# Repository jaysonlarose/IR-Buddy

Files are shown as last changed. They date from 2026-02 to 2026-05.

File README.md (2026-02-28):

# IR-Buddy

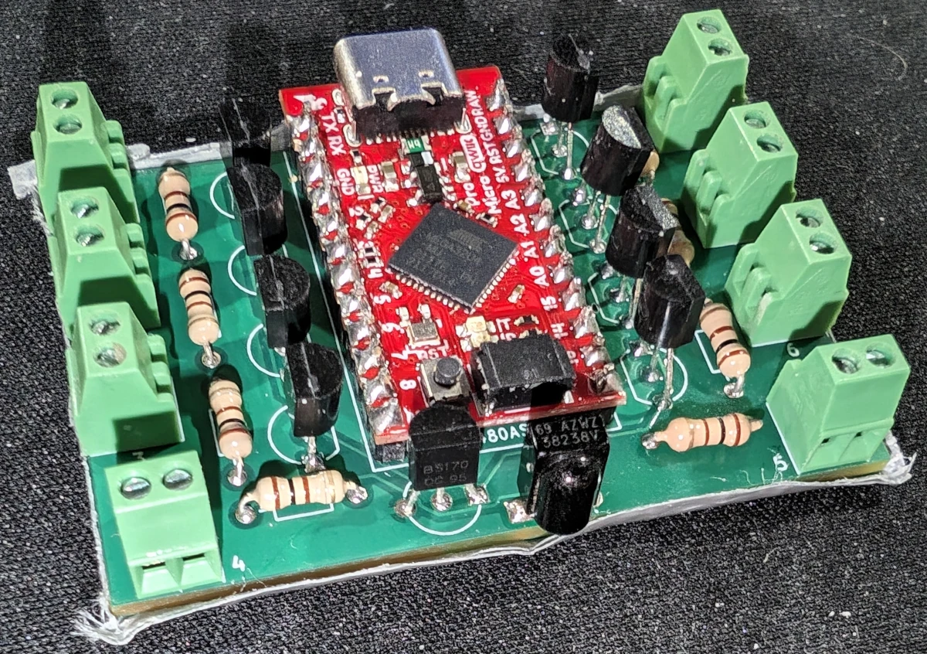
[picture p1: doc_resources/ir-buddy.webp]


A Thing That Does IR Remote Stuff.

## Easy To Use

IR-Buddy presents itself to a host computer as a USB Serial device and uses a simple, straightforward ASCII protocol. You can open up the device using a terminal emulator and get started right away, or you can build it into an automation system. Capturing and replaying an IR code is as easy as pointing the remote at IR-Buddy, hitting the button, and copy-pasting the output back into the terminal.

## Smart, But Not Too Smart

IR-Buddy has a couple of power features for those that want to use them. It understands the concept of codes that repeat a certain sequence when the button is held down, to make tasks like changing volume go more smoothly. The output frequency can be tweaked to a certain extent to satisfy receivers that may be slightly finicky. It has screw terminals to accept up to eight emitter LEDs, which can be individually enabled or disabled, handy for when you have multiple devices that react to the same code. All of these features are completely optional.

What do I mean by "not too smart"? IR-buddy doesn't have a concept of what *type* of code it's sending or receiving. It doesn't know NEC protocol from JVC protocol from RC5. It just sees a bunch of ON-OFF transitions, and that's what it gives you. When you want to send a code, you tell it the timing of how to send these ON-OFF transitions, and it'll do it. If you want to get fancy with interpreting or synthesizing these ON-OFF timing pairs, that's your prerogative.

## Protocol Details

IR-buddy communicates as a standard USB Serial device using the ASCII character set. Line termination is UNIX-style, using just the linefeed character (0x0a). You may need to fiddle around with your terminal emulator software to get this dialed in.

### IR Reception

Whenever IR-Buddy isn't actively receiving a code to send or sending one, it's monitoring the IR receiver for activity. When it finishes receiving one, it will print out a message that looks like this:

```
IR <ondur> <offdur> <ondur> <offdur> <...> <ondur>\n
```

`<ondur>` is the length of time that the modulated IR carrier was detected ("MARK" time), in microseconds.

`<offdur>` is the length of time that the modulated IR carrier was absent ("SPACE" time), in microseconds.

Example

I've got a CRT TV. It's an Advent somethingorother that I bought off eBay. It didn't come with a remote, so I had to buy one off eBay as well, but I digress. When I point the remote at the IR-buddy and give the power button a good press, I get:

```
IR 15866 450 1650 500 1650 500 1650 500 550 500 550 500 550 500 1650 500 550 500 550 500 1650 500 550 500 550 500 550 450 600 500 550 500 550 600
IR 22850 500 1650 450 1700 500 1650 500 500 500 550 500 550 500 1650 500 550 500 550 500 1650 500 550 500 550 500 550 500 550 500 550 500 550 600
IR 22800 500 1650 500 1650 500 1650 500 550 500 550 500 550 500 1650 500 550 500 550 500 1650 500 550 500 550 500 550 450 600 500 550 500 500 650
IR 22800 500 1650 500 1650 500 1650 500 550 500 550 500 550 500 1650 500 500 500 550 500 1650 500 550 500 550 500 550 500 550 500 550 500 550 600
IR 22850 500 1650 500 1650 500 1650 500 550 500 500 500 550 500 1650 500 550 500 550 500 1650 500 550 500 550 500 550 500 550 500 550 500 550 600
```

(And the TV turns on.) Yes, five separate lines. Remote controls tend to be fairly chatty when you press the button, and the Arduino-IRremote library that powers IR-buddy splits out any code sequence with a gap longer than about 5 milliseconds into a separate transmission.

What you're looking at is a list of timings. All values are in microseconds.

The first number after "IR" is the amount of time since the end of the last detected transmission. This is provided for when you need to combine multiple transmissions together into a single code. I happen to know a bit about this TV, and that's exactly what we're going to need to do here, as I'll explain in a bit. But first, let's discuss the rest of the line.

The next number is the "mark" time. The number of microseconds that the 38KHz infrared carrier was detected. The next number is the "space" time, the duration of time that no carrier is being sent. After that is another "mark" time. Then another "space" time. And so on.

As I mentioned, I know a bit about this TV, and I know that you need to send a code at least twice to get it to pay attention to you. So we're going to combine two of these codes together. Take the first line, and remove the "IR" from the start of it along with the first number. Then, take the second line (minus the initial "IR") and add it to the end of the first line, like so:

```
1650 500 1650 500 1650 500 550 500 550 500 550 500 1650 500 550 500 550 500 1650 500 550 500 550 500 550 450 600 500 550 500 550 600 22850 500 1650 450 1700 500 1650 500 500 500 550 500 550 500 1650 500 550 500 550 500 1650 500 550 500 550 500 550 500 550 500 550 500 550 600
```

Copy and paste this line back into the terminal emulator. You may need to press "enter" at the end as well. You should get back a line saying "RX OK". And if you're me, your TV will turn back off.

### IR Transmission

Well, we already sent our first IR code in the previous section, but I'll go into more detail here. In its simplest form, sending an IR code is just a matter of entering a quantity of "on duration", "off duration" numbers, separated by spaces, followed by a newline (aka pressing "return").

As soon as you enter a numeric character, IR-buddy will print out "RX " followed by the quantity of timing values entered thusfar. Each time you press space to start a new timing value, it will update the quantity. When you press return, it will respond with "OK" followed by a newline and transmit the code.

#### Repeat Codes

Most remotes have some sort of method of telling the thing on the other end of the room that a button is being held down. Sure, you can just send the code over and over again, but it just won't be as seamless as being able to act like the original. That's where repeat codes come in.

A ton of remotes use what's called the NEC protocol (or one of derivatives of the NEC protocol). Long story short, codes start with a 9 millisecond "attention" mark, followed by 4.5 milliseconds of space, then approximately 54 milliseconds of the actual remote data. As long as the button that initiated the code is held down, the remote announces this by sending an additional set of (9ms mark, 2.25ms space, 560 microsecond mark) every 110 milliseconds.

Here's what this looks like from IR-Buddy's perspective, using the "volume up" button on an old LG television remote as an example:

```
IR 434500 9050 4500 600 500 600 550 600 1650 600 500 600 550 600 550 600 500 600 550 600 1650 600 1650 600 500 600 1650 600 1650 600 1650 600 1650 600 1650 600 550 600 1650 600 550 600 500 600 550 600 500 600 550 600 550 600 1650 600 500 600 1650 600 1650 600 1650 600 1650 600 1650 600 1650 600
IR 40200 9050 2250 600
IR 96500 9100 2200 600
IR 96500 9100 2200 600
IR 96550 9050 2250 600
IR 96500 9050 2250 600
```

Just like the protocol describes, we see a bunch of data, followed by about 40 milliseconds of silence. Then we see the first repeat burst, followed by about 96 milliseconds of silence, then the next, and so on, and so forth.

Instructing IR-Buddy to send a code along with a repeat sequence looks like this:

```
<ondur> <offdur> <ondur> <offdur> ... <ondur> <offdur> R <ondur> <offdur> ... <ondur> <offdur>
```

So, a set of mark/space timings, ending with space, followed by "R", followed by another set of mark/space timings, ending with space.

IR-buddy will send the first set of timings, and then repeat the second set of timings until it receives another character from the terminal. It will respond with "REPEAT" instead of "OK" to announce this. When you want the repeating to stop, send any character to IR-buddy. It will respond with "OK", and return to normal operations.

Returning back to the LG volume key, this is what we'll paste to replicate its behavior:

```
9050 4500 600 500 600 550 600 1650 600 500 600 550 600 550 600 500 600 550 600 1650 600 1650 600 500 600 1650 600 1650 600 1650 600 1650 600 1650 600 550 600 1650 600 550 600 500 600 550 600 500 600 550 600 550 600 1650 600 500 600 1650 600 1650 600 1650 600 1650 600 1650 600 1650 600 40200 R 9050 2250 600 96500
```

To explain how to construct this... Take the first line we received and throw away the first value, like we've done before. The code we've got so far ends on a mark. When not using repeat codes, IR-buddy is lenient and doesn't care whether you end on a mark or a space, but when using repeat codes you always need to end on a space. So we tack the 40 milliseconds of space from the next portion of the code onto the end of what we've got so far, and then follow it up with the "R" repeat declaration. This will take care of that weirdly timed first repeat burst, so all we need to add after the repeat declaration is the 9050 mark, 2250 space, 600 mark and finally ending with the 96500 space to finish up the 110ms repeat.

#### Output LED Muxing

You may have noticed that there are separate screw terminals for attaching infrared LEDS to, and that each one has a little number next to it, from 1 to 8. This isn't just so you can spam your remote codes in all directions at once, though you *can* use it that way, if you want.

Or, consider this scenario: You've got three of the same model of TV sitting in the same room, and you only want to control a specific television while leaving the other two alone. That's exactly what setting the LED mux is for.

Using a pair of wires, you can run a LED from each of the terminals to its own dedicated television, taping it to the IR receiver with something like duct tape to ensure that each television only sees the LED that's attached to it. You can then specify which LED — or combination of LEDs — that you want a particular code to be sent to.

To make our example easy, let's say that TV 1 is being serviced by the LED in terminal 1, TV 2 by terminal 2, and TV 3 by terminal 3. Now we just want to send a code to TV 2.

Pin muxing is handled by an 8-bit binary value. Terminal 1 is activated by bit 0, terminal 2 by bit 1, terminal 3 by bit 2... all the way up to terminal 8, activated by bit 7:

| Terminal Label | Bit Number | Decimal Value |
| --- | --- | --- |
| 1 | 0 | 1 |
| 2 | 1 | 2 |
| 3 | 2 | 4 |
| 4 | 3 | 8 |
| 5 | 4 | 16 |
| 6 | 5 | 32 |
| 7 | 6 | 64 |
| 8 | 7 | 128 |

Specifying a mux value to use for a particular code is done by prepending the code with the mux value followed by the mux designator, "M":

```
<muxval> M <ondur> <offdur> <ondur> <offdur> ... <ondur>
```

The value is specified in decimal. So, sending a code just to our hypothetical TV 2 will look like:

```
2 M 9050 4500 600 500 600 550 etc
```

To send to TV 1 and 3 but not 2:

```
5 M 9050 4500 600 500 600 550 etc
```

To send to every terminal except our three televisions:

```
248 M 9050 4500 600 500 600 550 etc
```

The default is a mux value of 255, as in all terminals are used. You can set a muxval if 0 if you *really* want to, but of course no code will make it out.

#### Output Frequency Tweaking

As alluded to previously, the vast majority of remote controls operate using a carrier frequency of 38 KHz, meaning that a mark timing isn't comprised of just shining the LED for a duration of time, but instead is made by blinking the LED on and off 38,000 times per second. If, for whatever reason, you need a different output frequency, you can change this on a per-code basis by using the "F" frequency declaration.

Setting the default 38 KHz frequency would look like:

```
38 F 9050 4500 600 500 600 550 etc
```

Another popular frequency is 40 KHz. Most devices that expect 40KHz will respond just fine to 38KHz, but if you've got a finnicky device, then you can try 40 KHz like so:

```
40 F 9050 4500 600 500 600 550 etc
```

To be fully honest, this is just passing through the functionality that was provided by what few remnants of the original Arduino-IRremote libarary remain, and I'm just providing it in case somebody needs it.

### Switching between "ANSI" and "ASCII" output

By default, IR-Buddy does some trickery with ANSI escape codes to display the running count of timing values entered. If you don't like this for whatever reason, you can switch between ANSI output, straight ASCII output, and back by sending "A".

### Binary protocol

Maybe only using 7 out of every 8 bits isn't your style. Maybe you want something a tiny bit more machine-readable. If so, then the binary protocol might be right up your alley!

#### Opcodes

| opcode name | hex value |
| --- | --- |
| OP_IR_TRANSMIT  | 0x01 |
| OP_IR_RECEIVE | 0x02 |
| OP_EXIT_BINARY  | 0x03 |
| OP_ACK | 0x04 |
| OP_NAK | 0x05 |
| OP_REPEATING | 0x06 |
| OP_ENTER_BINARY | 0xff |

All opcodes are kind of mushed together. Some of these (OP_IR_TRANSMIT, OP_ENTER_BINARY, OP_EXIT_BINARY) are sent *to* ir-buddy to request an action. Some (OP_IR_RECEIVE) are sent *from* ir-buddy to announce events. Some (OP_ACK, OP_NAK, OP_REPEATING) are sent from ir-buddy to announce the completion status of a request.

#### Timing division

Timing values are expressed using 16 bit unsigned integers (this is also how they're stored internally, well, for the most part). Normally this would only give you values between 0 and 65,535 microseconds, which is not long enough for many timing durations, so all of these values are divided by 10. This happens in the background and is transparent to you in ASCII mode, but that isn't the case for binary mode since we're using 16 bit unsigned integers here, too. So when you're transmitting a code, be sure to divide each of the timing values by 10 first, and whenever you're receiving a code, expect that you'll need to multiply each of the timing values you receive by 10.

#### Switching to Binary Protocol

Send OP_ENTER_BINARY. Expect a response of OP_ACK.

#### Returning back to ASCII/ANSI Protocol

Send OP_EXIT_BINARY (which is also the equivalent of entering CTRL+C repeatedly at a terminal) until you start getting ASCII "CANCEL" responses.

#### Sending an IR code

This one's a whole-ass packet.

| Name | Length | Description |
| --- | --- | --- |
| OP_IR_TRANSMIT | 8 bits | Tells IR-Buddy that you want to send an IR code |
| mux | 8 bits | mux value |
| freq | 8 bits | transmit frequency (KHz) |
| codelen | 16 bits | quantity of values comprising the timings for the non-repeat part of the code |
| repeatlen | 16 bits | quantity of values comprising the timings for the repeating part of the code  |
| code timings | 16 bits x codelen | divided timing values for the non-repeat part of the code |
| repeat timings | 16 bits x repeatlen | divided timing values for the repeating part of the code |

All 16-bit values are big-endian bit order, i.e., you send the high byte followed by the low byte.

Remember that all timing values should be divided by 10 before they're converted to 16 bit values.

IR-buddy will respond with OP_ACK for codes that don't have a repeat section, or OP_REPEATING for codes that do. The code will repeat until you send a byte of data (the contents of which don't matter), after which IR-buddy will send back OP_ACK.

#### Receiving an IR code

| Name | Length | Description |
| --- | --- | --- |
| OP_IR_RECEIVE | 8 bits | IR-Buddy announcing it's about to send an IR code |
| codelen | 16 bits | quantity of timing values that are to follow |
| code timings  | 16 bits x codelen | divided timing values |

All 16-bit values are big-endian bit order, meaning you'll receive the high byte followed by the low byte.

Remember that all timing values are divided by 10, so you'll need to multiply them by 10 afterwards.

## Making Your Own

Inside the "board" subdirectory, you'll find the KiCad project, schematic, PCB layout, and associated library components, along with "bom.txt", which is the Bill of Materials. If you want to skip messing around with all the KiCad stuff, then you can upload "board/gerbers/gerbers.zip" to your favorite PCB manufacturing house.



Each of the eight IR emitters has its own section, which consists of a screw terminal, a resistor, and a BS170 transistor. The above diagram shows which components are associated with each other.

Note that in the Bill of Materials, the quantity of screw terminals, transistors, resistors, and LEDs is variable. If you only intend to use a single IR LED emitter, then of course it doesn't make any sense for you to populate the other 7 slots.

The BS170 transistor in the center of the board connects the microcontroller's IR output pin to the source of all of the other transistors, so it is mandatory. Likewise, IR reception will obviously not work if you don't solder in the IR receiver.

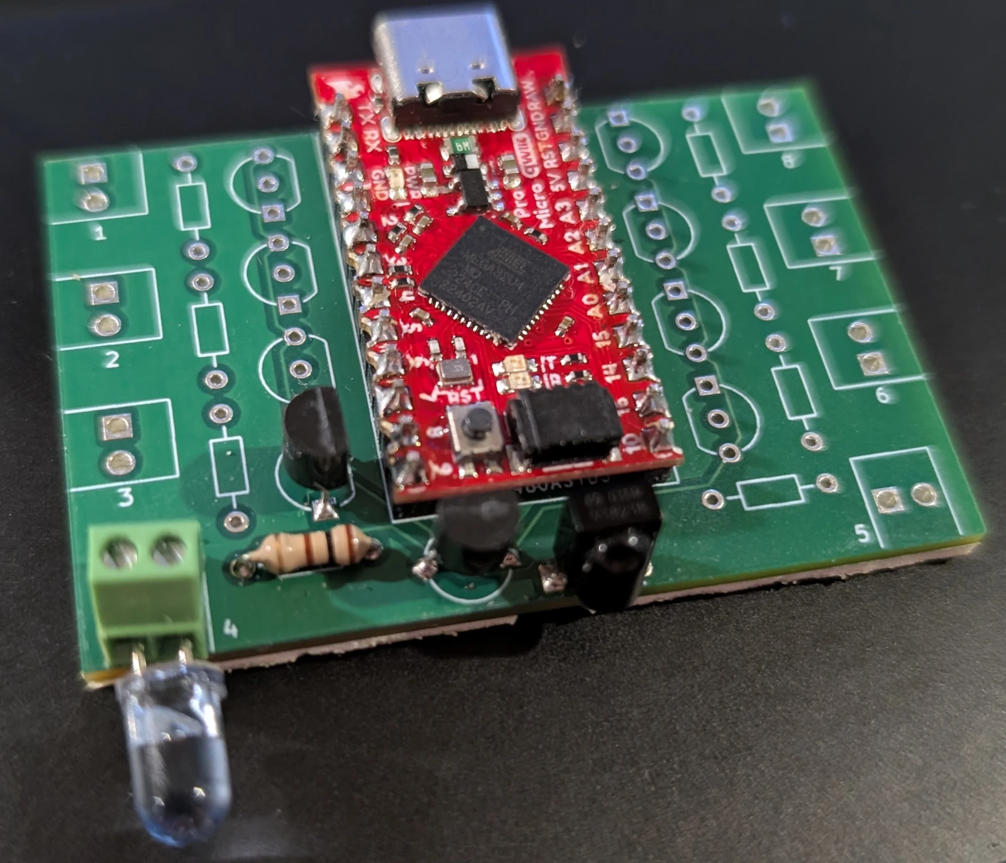
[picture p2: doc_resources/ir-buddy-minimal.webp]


Here's an example of a minimum-configuration IR-Buddy.

### Building and Installing the Firmware

#### Using arduino-mk

The development enviroment I use for building "Arduino" firmware is made up of a Debian-based Linux distribution with the "arduino" and "arduino-mk" packages installed. If you're familiar with what this is, then you should be basically good to go. Plug in the Sparkfun Pro Micro via USB, check `dmesg` to see what /dev entry it got assigned, update Makefile to match, run `make` and `make upload`.

#### Using the Arduino IDE

I've tweaked the file and directory names in such a way that this will work in the Arduino IDE as well. 

* Plug the Sparkfun Pro Micro board in via USB.
* Menu to "File -> Open". Navigate to and open firmware/firmware.ino.
* Menu to "Tools -> Board -> Arduino AVR Boards" and select "Arduino Leonardo".
* Menu to "Port" and choose the appropriate port that the Pro Micro board is on.
* Click the "Verify" button to build. Ignore the "Low memory available. stability problems may occur." warning.
* Click the "Upload" button.

#### Uploading the Provided .hex File Using Avrdude

Or, if you're happy with the firmware as I built it and are slightly hardcore, you can just upload the firmware_.hex file that this repository ships with and call it a day.

* Plug the Sparkfun Pro Micro board in via USB.
* Doubleclick the board's reset button to put it into firmware update mode.
* Run something very similar to the following:

```bash
avrdude -q -V -p atmega32u4 -C /etc/avrdude.conf -D -c avr109 -b 57600 -P /dev/ttyACM2 -U flash:w:firmware_.hex:i
```

I say "similar to" because I don't know where your avrdude.conf file is located, nor do I know how to refer to the serial port that the Pro Micro board will show up as.

## License

At the end of the day, this is all just a bunch of bits. I don't care what you do with it. I also take no responsibility for what you do with it. Except for anything in the lib/firmware directory. Those bits, heavily modified as they may be, have had a software license attached to them.

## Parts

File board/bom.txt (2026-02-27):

Microcontroller: Sparkfun Pro Micro (5V/16MHz)
Quantity: 1
https://www.sparkfun.com/sparkfun-qwiic-pro-micro-usb-c-atmega32u4.html
https://www.sparkfun.com/pro-micro-5v-16mhz.html

Screw terminals: 2-pin 2.54mm pitch
Quantity: 1-8
https://www.sparkfun.com/screw-terminals-2-54mm-pitch-2-pin.html

Transistors: BS170
Quantity: 2-9
https://www.jameco.com/z/BS170-Major-Brands-Transistor-BS170-TO-92-Transistor-N-Channel-MOSFET-60-Volt_256031.html
https://www.mouser.com/ProductDetail/onsemi/BS170?qs=FOlmdCx%252BAA0Q%252B3zvwxJUKQ%3D%3D

Resistors: 100 Ohm 5% 1/4 watt (or to taste)
Quantity: 1-8
https://www.jameco.com/z/CF1-4W101JRC-PC-Jameco-ValuePro-Carbon-Film-Resistor-100-Ohm-5-1-4-Watt-250mW-POCO-Club-10-Pack-_2758551.html

IR Receiver: Vishay TSOP38288
Quantity: 1
https://www.adafruit.com/product/157

IR LED
Quantity: 1-8
https://www.adafruit.com/product/388

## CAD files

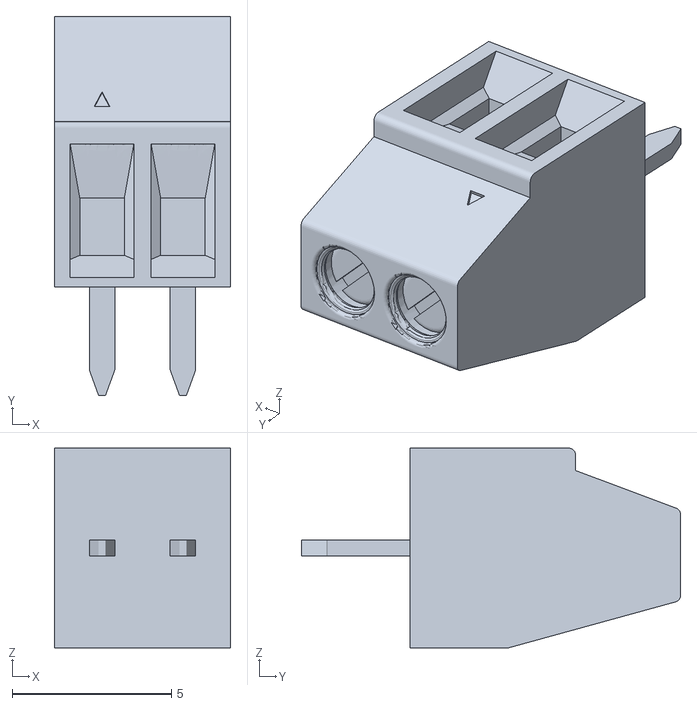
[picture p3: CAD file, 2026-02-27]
board/3D Models/termblock2.stl
5.53 x 11.9 x 6.27

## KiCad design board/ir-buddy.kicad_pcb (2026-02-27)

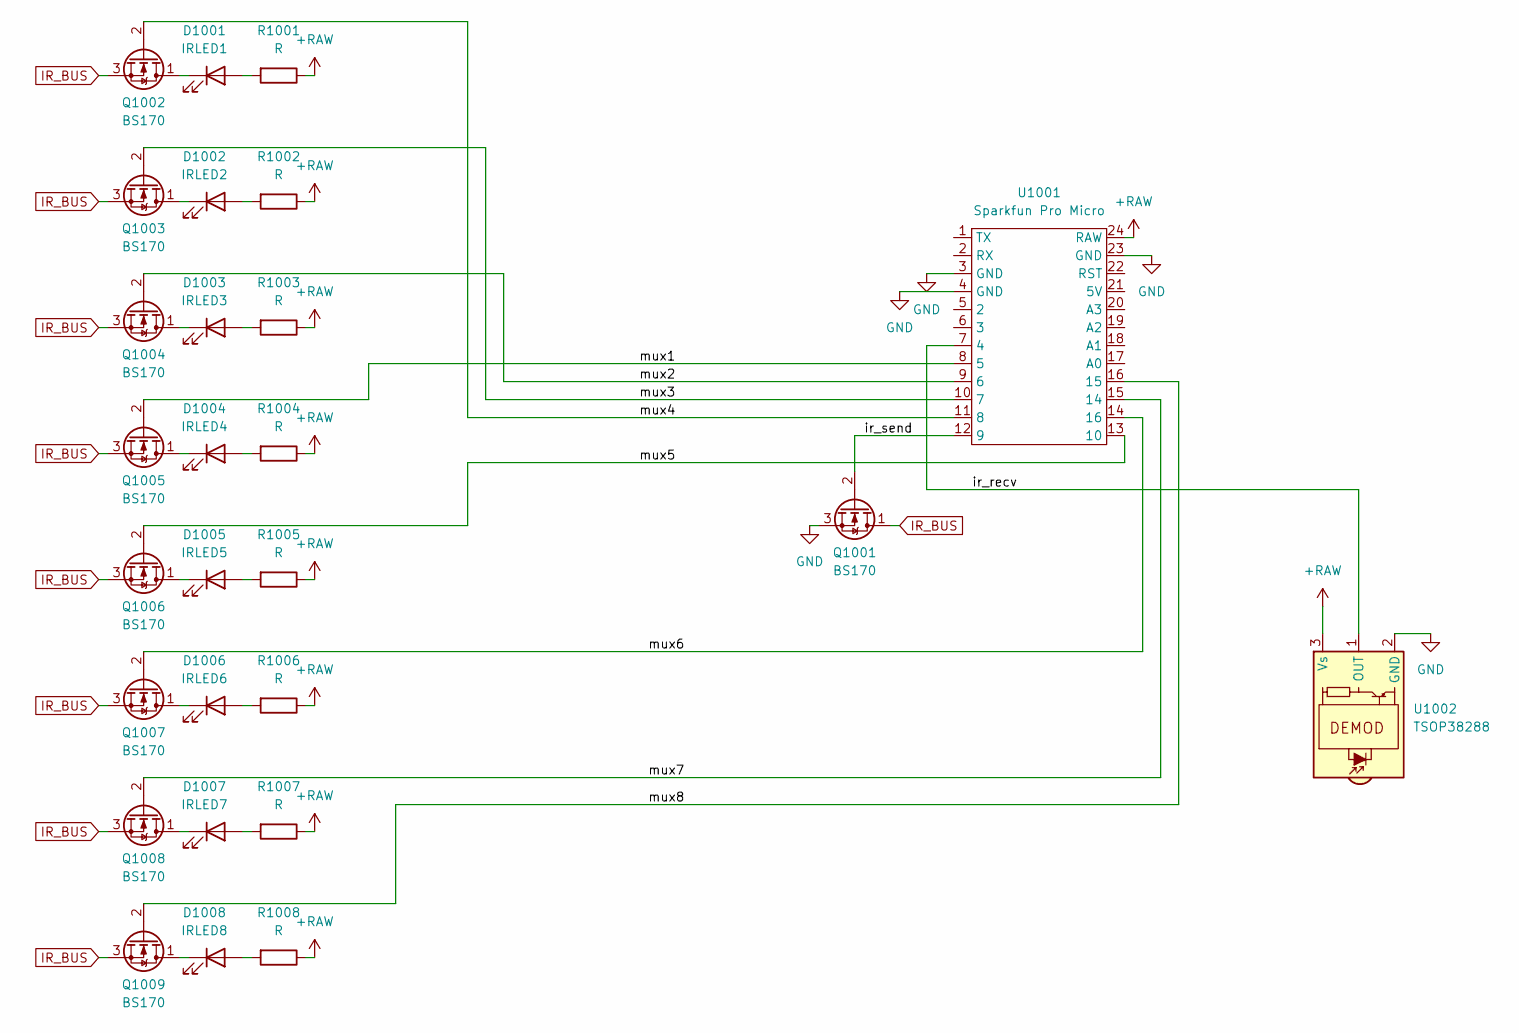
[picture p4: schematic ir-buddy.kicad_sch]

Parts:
D1001: IRLED1; Screw_Terminal_2.54mm_x_2
D1002: IRLED2; Screw_Terminal_2.54mm_x_2
D1003: IRLED3; Screw_Terminal_2.54mm_x_2
D1004: IRLED4; Screw_Terminal_2.54mm_x_2
D1005: IRLED5; Screw_Terminal_2.54mm_x_2
D1006: IRLED6; Screw_Terminal_2.54mm_x_2
D1007: IRLED7; Screw_Terminal_2.54mm_x_2
D1008: IRLED8; Screw_Terminal_2.54mm_x_2
Q1001, Q1002, Q1003, Q1004, Q1005, Q1006, Q1007, Q1008, Q1009: BS170; TO-92_Inline_spread_pins
R1001, R1002, R1003, R1004, R1005, R1006, R1007, R1008: R; R_Axial_DIN0204_L3.6mm_D1.6mm_P7.62mm_Horizontal
U1001: Sparkfun Pro Micro; Sparkfun_Pro_Micro
U1002: TSOP38288; Vishay_MINICAST-3Pin

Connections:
+RAW: R1001.1, R1002.1, R1003.1, R1004.1, R1005.1, R1006.1, R1007.1, R1008.1, U1001.24 (RAW), U1002.3 (Vs)
/ir_recv: U1001.7 (4), U1002.1 (OUT)
/ir_send: Q1001.2 (G), U1001.12 (9)
/mux1: Q1005.2 (G), U1001.8 (5)
/mux2: Q1004.2 (G), U1001.9 (6)
/mux3: Q1003.2 (G), U1001.10 (7)
/mux4: Q1002.2 (G), U1001.11 (8)
/mux5: Q1006.2 (G), U1001.13 (10)
/mux6: Q1007.2 (G), U1001.14 (16)
/mux7: Q1008.2 (G), U1001.15 (14)
/mux8: Q1009.2 (G), U1001.16 (15)
GND: Q1001.3 (S), U1001.3 (GND), U1001.4 (GND), U1001.23 (GND), U1002.2 (GND)
IR_BUS: Q1001.1 (D), Q1002.3 (S), Q1003.3 (S), Q1004.3 (S), Q1005.3 (S), Q1006.3 (S), Q1007.3 (S), Q1008.3 (S), Q1009.3 (S)
unnamed: D1001.2 (A), R1001.2
unnamed: D1001.1 (K), Q1002.1 (D)
unnamed: D1002.2 (A), R1002.2
unnamed: D1002.1 (K), Q1003.1 (D)
unnamed: D1003.2 (A), R1003.2
unnamed: D1003.1 (K), Q1004.1 (D)
unnamed: D1004.2 (A), R1004.2
unnamed: D1004.1 (K), Q1005.1 (D)
unnamed: D1005.2 (A), R1005.2
unnamed: D1005.1 (K), Q1006.1 (D)
unnamed: D1006.2 (A), R1006.2
unnamed: D1006.1 (K), Q1007.1 (D)
unnamed: D1007.2 (A), R1007.2
unnamed: D1007.1 (K), Q1008.1 (D)
unnamed: D1008.2 (A), R1008.2
unnamed: D1008.1 (K), Q1009.1 (D)

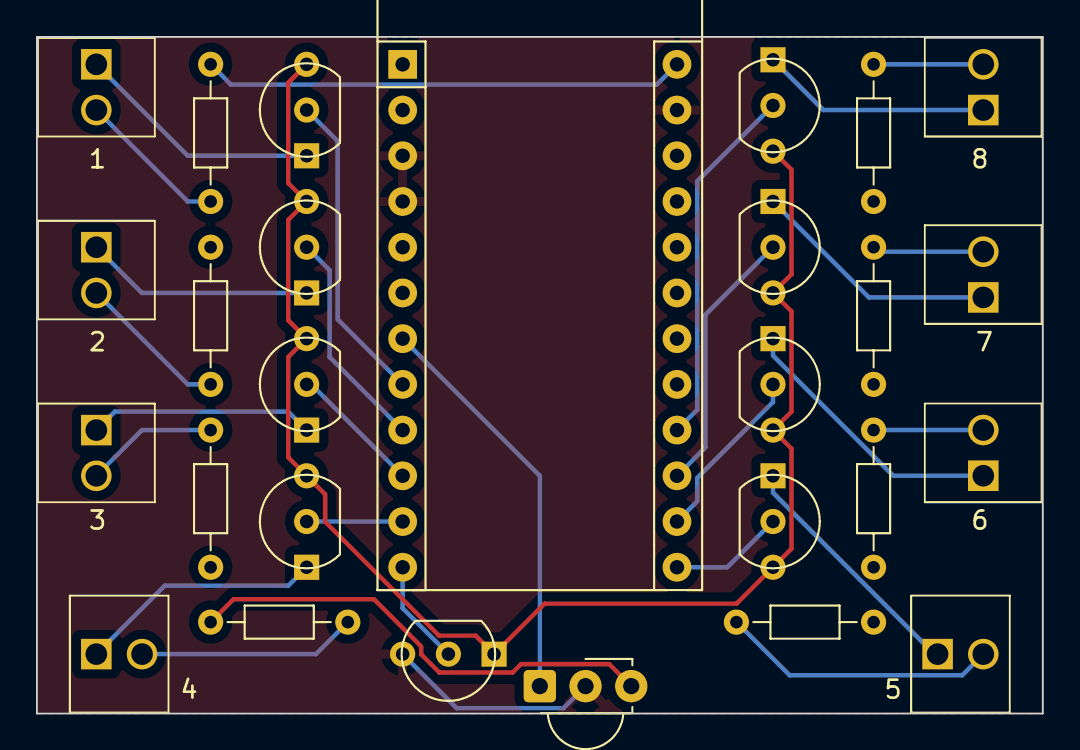
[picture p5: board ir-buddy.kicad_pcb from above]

Board: 2 copper layers, 55.9 x 37.6 mm, 27 parts (0 on the bottom side), 29 nets.

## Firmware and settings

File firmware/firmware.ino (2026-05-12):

#include "src/Arduino-IRremote2/IRremote.h"
#include "src/Arduino-IRremote2/IRremoteInt.h"
#include <avr/pgmspace.h>

#undef IRRECV_PIN
#ifdef __AVR_ATmega644P__
#define IRRECV_PIN 12
#endif

#ifndef IRRECV_PIN
#define IRRECV_PIN 4
#endif

#ifdef IRRECV_PIN
decode_results results;
IRrecv irrecv(IRRECV_PIN, 13);
#endif

// In order to fit the longer durations into uint16_t, we divide incoming durations by this value in ASCII mode.
// In binary mode, all incoming code durations must be predivided by this value.
// Note that IR reception is further constrained by the USECPERTICK def, which comes out of the box as 50.
// In binary mode, the appropriate math is performed so that the values sent over the line conform to the CODE_DIV division and not USECPERTICK.
#define CODE_DIV 10
#define SETTLE_DURATION 5000

#define OP_IR_TRANSMIT  0x01
#define OP_IR_RECEIVE   0x02
#define OP_EXIT_BINARY  0x03
#define OP_ACK          0x04
#define OP_NAK          0x05
#define OP_REPEATING    0x06
#define OP_ENTER_BINARY 0xff

#undef DEBUG_MUX

int code_mult_binary;

IRsend irsend;


// binary_mode is set to 1 when '\xff' is received, which puts the logic into binary protocol mode.
uint8_t ansi_mode = 1;
uint8_t binary_mode = 0;
uint8_t binary_mux = 0;
uint8_t binary_freq = 0;
uint16_t binary_codelen = 0;
uint16_t binary_repeatlen = 0;
// codepos stores the length of entries in codebuf that comprise the primary code.
uint16_t codepos = 0;
bool printed_rx = false;
// charbuf stores incoming ASCII characters from the UART.
// As parsing occurs in realtime, no more than 8 bytes are needed.
char charbuf[8];
uint8_t charpos = 0;

// non-repeating code (repeatstate == 0):
// 0 -> codepos
//
// simple repeat (repeatstate == 1):
// 0 -> codepos -> repeatpos

uint8_t repeatstate = 0;
uint16_t repeatpos = 0;

// Emitter carrier frequency in kHz
int emitfreq = 38;
uint8_t muxval = 0xff;

extern volatile irparams_t irparams;

#ifdef IRRECV_PIN
// When a full incoming IR transmission has been received, IR-buddy
// will spit it out like so:
// IR ONDUR OFFDUR ONDUR OFFDUR ETC ETC ONDUR\n
// "IR" is the literal ascii characters "IR".
// ONDUR and OFFDUR come in pairs, corresponding to the amount of
// time the intercepted pulse was ON and OFF, in microseconds.
// End of reception is indicated with a newline.  Easy peasy.
void dump(decode_results *results) {
	Serial.print(F("IR"));
	for (uint16_t i = 0; i < results->rawlen; i++) {
		Serial.print(' ');
		Serial.print((unsigned long) results->rawbuf[i] * USECPERTICK);
	}
	Serial.println("");
}

void dump_binarymode(decode_results *results) {
	// send opcode
	Serial.write(OP_IR_RECEIVE);
	// send results length
	Serial.write((uint8_t) (results->rawlen >> 8));
	Serial.write((uint8_t) (results->rawlen & 0xff));
	// send code timings
	for (uint16_t i = 0; i < results->rawlen; i++) {
		//// Multiply to convert from USCEPERTICK division to CODE_DIV division
		uint16_t val_binary = results->rawbuf[i] * code_mult_binary;
		// Send her down the line big-endian stylee.
		Serial.write((uint8_t) (val_binary >> 8));
		Serial.write((uint8_t) (val_binary & 0xff));
	}
}
		
#endif

const uint8_t PROGMEM irmux_to_pin_PGM[] = { 5, 6, 7, 8, 10, 16, 14, 15 };

void set_irmux(uint8_t mux) {
	for (uint8_t i = 0; i < 8; i++) {
		uint8_t muxpin = pgm_read_byte(irmux_to_pin_PGM + i);
		if (muxpin != 0) {
			#ifdef DEBUG_MUX
			if (!binary_mode) {
				Serial.print(F("MUX pin "));
				Serial.print(muxpin);
			}
			#endif
			if ((mux & (1 << i)) > 0) {
				digitalWrite(muxpin, HIGH);
				#ifdef DEBUG_MUX
				if (!binary_mode) {
					Serial.println(F(" HIGH"));
				}
				#endif
			} else {
				digitalWrite(muxpin, LOW);
				#ifdef DEBUG_MUX
				if (!binary_mode) {
					Serial.println(F(" LOW"));
				}
				#endif
			}
		}
	}
}

// Reimplementation of IRsend::mark, because the Arduino-IRremote version is
// constrained to unsigned int.
void mark_long(IRsend sender, unsigned long time) {
	TIMER_ENABLE_PWM;
	if (time > 0) {
		sender.custom_delay_usec(time);
	}
}

// Reimplementation of IRsend::space, because the Arduino-IRremote version is
// constrained to unsigned int.
void space_long(IRsend sender, unsigned long time) {
	TIMER_DISABLE_PWM;
	if (time > 0) {
		sender.custom_delay_usec(time);
	}
}


void setup() {
	Serial.begin(115200);
	// Set multiplier to use in binary mode to convert Arduino-IRremote's
	// raw USECPERTICK format to my CODE_DIV format.
	code_mult_binary = USECPERTICK / CODE_DIV;
	// make rawbuf_a the active buffer.
	irparams.rawbuf = irparams.rawbuf_a;
	// set mux pin direction to output
	for (uint8_t i = 0; i < 8; i++) {
		uint8_t muxpin = pgm_read_byte(irmux_to_pin_PGM + i);
		if (muxpin != 0) {
			pinMode(muxpin, OUTPUT);
		}
	}
	// initial mux
	set_irmux(0xff);
	irsend.enableIROut(binary_freq);
	space_long(irsend, SETTLE_DURATION);
	#ifdef IRRECV_PIN
	// set the receive pin direction to INPUT
	pinMode(IRRECV_PIN, INPUT);
	// start the receiver
	irrecv.enableIRIn();
	#endif
}

// Reimplementation of IRsend::sendraw, which multiplies all code durations by
// a supplied factor.
void sendraw_mult(IRsend sender, volatile unsigned int buf[], unsigned int len, unsigned int multiplier) {
	//Serial.println("SENDING");

	for (unsigned int i = 0; i < len; i++) {
		unsigned long duration = (unsigned long) buf[i] * multiplier;
		if (i & 1) {
			space_long(sender, duration);
		} else {
			mark_long(sender, duration);
		}
	}

	space_long(sender, 0);
}

// Pulled rawval out into a global variable so that we can persist
// the value around in case we need to use it as a frequency specifier.
unsigned long rawval = 0;


// IR emit format
// ON + ' ' + OFF + ' ' + ON + ' ' + OFF + ' ' + etc etc + ON + '\r\n'
// ON and OFF are strings of ascii characters '0'-'9' defining the
// mark durations and space durations, in microseconds.

//
// [ON + ' ' + OFF + ' ' + ON + ' ' + OFF + ' ' + etc etc + ON] + OFF1 + ' R ' + [ON + ' ' + OFF + ' ' + etc etc + OFF2] + '\r\n'
// Send the code between the first set of brackets
// delay OFF1 microseconds
// then continually repeat the code between the second set of brackets until an additional character is received on serial.

// on off on off on off on off r on off on off
// codepos = 8
// repeatpos = 4


// Binary protocol
// The host sends 0xff to initiate binary protocol.
// Sending an IR transmission request:
// 0x01 (Start of Heading) + 8-bit frequency + 8-bit mux + 8-bit codelen + 8-bit repeatlen + 0x02 (Start of Text) + (series of 16-bit big-endian code durations*) + (series of 16-bit repeat durations*) + 0x03 (End of Text)
// * All of these code durations should be divided by 10 before transmission.
// Leaving binary protocol:
// Keep sending 0x03 (CTRL+C on most terminal emulators) until you start getting ANSI back.

//int ram_avail() {
//	extern int __bss_end;
//	extern void *__brkval;
//	int free_memory;
//	if ((int) __brkval == 0) {
//		free_memory = ((int) &free_memory) - ((int) &__bss_end);
//	} else {
//		free_memory = ((int) &free_memory) - ((int) __brkval);
//	}
//	return free_memory;
//}

void parser_reset() {
	if (binary_mode) {
	} else {
		//set_irmux(0xff);
		muxval = 0xff;
		#ifdef IRRECV_PIN
		irrecv.enableIRIn();
		#endif
		codepos = 0;
		charpos = 0;
		repeatpos = 0;
		repeatstate = 0;
		emitfreq = 38;
		printed_rx = false;
		// cursor_horizontal_absolute(1) + save_cursor_position
		if (ansi_mode) {
			Serial.print(F("\x1b[1G\x1b[s"));
			Serial.flush();
		}
	}
}

uint8_t recv_8bit() {
	while (!Serial.available()) {
	}
	char c = Serial.read();
	return (uint8_t) c;
}

uint16_t recv_16bit() {
	uint16_t ret = 0;
	ret |= recv_8bit() << 8;
	ret |= recv_8bit();
	return ret;
}

	

void loop() {
	#ifdef IRRECV_PIN
	// Do not process IR events if we're receiving serial data.
	// This is done just to make automating the thing nice and
	// predictable:
	// If you want to send something, send something.
	// If there's a partial code in the receive buffer,
	// it'll be nuked. After the buddy has finished
	// flushing the serial buffer and sending the code,
	// IR receive will resume until the next time you
	// start to send serial data.
	// Note: When you start sending serial data, ir-buddy will
	// respond to the first character with "RX ", to let you know
	// that it sees you're sending it something, and that it's
	// no longer listening for IR. When you finish transmission by
	// issuing a newline, IR-buddy will acknowledge with either "OK\n"
	// or "ERROR".
	// Thus, if you read back "RX" and what you really want to do
	// is listen for IR, throw it a ^C (0x03) to cancel. IR-buddy
	// will confirm with "CANCEL\n".
	if (codepos == 0 && charpos == 0) {
		if (irrecv.decode(&results)) {
			if (binary_mode) {
				dump_binarymode(&results);
			} else {
				dump(&results);
			}
			irrecv.resume();
		}
	}
	#endif
	while (Serial.available()) {
		uint8_t c = Serial.read();
		if (binary_mode) {
			if (c == OP_IR_TRANSMIT) {
				irrecv.pause();
				binary_mux = recv_8bit();
				binary_freq = recv_8bit();
				binary_codelen = recv_16bit();
				binary_repeatlen = recv_16bit();
				for (uint16_t i = 0; i < binary_codelen + binary_repeatlen; i++) {
					irparams.rawbuf[i] = recv_16bit();
				}
				set_irmux(binary_mux);
				if (binary_repeatlen > 0) {
					Serial.write(OP_REPEATING);
				} else {
					Serial.write(OP_ACK);
				}
				irsend.enableIROut(binary_freq);
				space_long(irsend, SETTLE_DURATION);
				sendraw_mult(irsend, irparams.rawbuf, binary_codelen, CODE_DIV);
				if (binary_repeatlen > 0) {
					while (!Serial.available()) {
						sendraw_mult(irsend, irparams.rawbuf + binary_codelen, binary_repeatlen, CODE_DIV);
					}
					Serial.read();
					Serial.write(OP_ACK);
				}
				irrecv.enableIRIn();
			} else if (c == OP_ENTER_BINARY) {
				Serial.write(OP_ACK);
			} else if (c == OP_EXIT_BINARY) {
				binary_mode = 0;
			}
			parser_reset();
		} else {
			if (c == OP_ENTER_BINARY) {
				binary_mode = 1;
				Serial.write(OP_ACK);
			// CTRL+C and ESC cancel input
			} else if (c == 0x03 || c == 0x1b) {
				// restore_cursor_position + erase_line_from_cursor + "CANCEL"
				if (ansi_mode) {
					Serial.print(F("\x1b[u\x1b[0K"));
				}
				Serial.println(F("CANCEL"));
				parser_reset();
			// Digits get fed into charbuf, where they'll get parsed into
			// binary values when ' ' or '\n' is encountered.
			} else if (c >= '0' && c <= '9') {
				if (codepos == 0 && charpos == 0 && !printed_rx) {
					Serial.print(F("RX "));
					irrecv.pause();
					if (ansi_mode) {
						// save_cursor_position
						Serial.print(F("\x1b[s"));
					}
					printed_rx = true;
				}
				if (ansi_mode && charpos == 0) {
					// restore_cursor_position
					Serial.print(F("\x1b[u"));
					Serial.print(codepos + repeatpos + 1);
				}
				charbuf[charpos] = c;
				if (charpos < 8) {
					charpos++;
				}
			// 'A' toggles between ANSI mode and ASCII mode
			} else if (c == 'A') {
				ansi_mode ^= 1;
				if (ansi_mode) {
					Serial.println(F("ANSI"));
				} else {
					Serial.println(F("ASCII"));
				}
				parser_reset();
			// 'R' deliniates the main body of an IR code from its repeat value
			} else if ((c == 'R') && charpos == 0) {
				repeatstate = 1;
			// 'F' specifies the previous value is to be used to set the PWM frequency
			} else if ((c == 'F') && charpos == 0 && repeatstate == 0 && codepos > 0) {
				// pull emitfreq from the persisted rawval
				emitfreq = rawval;
				// rewind codepos
				codepos--;
				// restore_cursor_position + "FREQ " + save_cursor_position
				if (ansi_mode) {
					Serial.print(F("\x1b[uFREQ \x1b[s"));
					Serial.print(codepos + repeatpos);
				}
			// 'M' specifies the previous value is to be used to set the muxing
			} else if ((c == 'M') && charpos == 0 && repeatstate == 0 && codepos > 0) {
				// here
				if (rawval > 255) {
					// restore_cursor_position + erase_line_from_cursor
					if (ansi_mode) {
						Serial.print(F("\x1b[u\x1b[0K"));
					}
					Serial.println(F("ERROR"));
					parser_reset();
				} else {
					muxval = (uint8_t) rawval;
					codepos--;
					// restore_cursor_position + "MUX " + save_cursor_position
					if (ansi_mode) {
						Serial.print(F("\x1b[uMUX \x1b[s"));
						Serial.print(codepos + repeatpos);
					}
				}
			// if charbuf has data in it, ' ' or '\n' prompt digestion of charbuf.
			} else if ((c == ' ' || c == '\n') && charpos > 0) {
				charbuf[charpos] = '\0';
				charpos = 0;
				rawval = strtoul(charbuf, NULL, 10);
				irparams.rawbuf[codepos + repeatpos] = (unsigned int) (rawval / CODE_DIV);
				if (repeatstate > 0) {
					repeatpos++;
				} else {
					codepos++;
				}
				// restore_cursor_position
				//Serial.print("\x1b[u");
				//Serial.print(codepos + repeatpos);
			// otherwise, extra spaces are a no-op
			} else if (c == ' ') {
			} else if (c == '\n') {
			// completely ignore carriage return.
			} else if (c == '\r') {
			} else {
				if (ansi_mode) {
					// restore_cursor_position + erase_line_from_cursor
					Serial.print(F("\x1b[u\x1b[0K"));
				}
				Serial.println(F("ERROR"));
				parser_reset();
			}

			// note this isn't an "else if"
			// '\n' finishes input and prompts action.
			if (c == '\n' && codepos > 0) {
				if (ansi_mode) {
					// restore_cursor_position + erase_line_from_cursor
					Serial.print(F("\x1b[u\x1b[0K"));
				}
				if (codepos + repeatpos == RAWBUF) {
					Serial.println(F("ERROR"));
				} else if (repeatpos > 0) {
					// This needs to be "% 2 == 0" because there's an off duration at the end.
					if (codepos % 2 != 0 || repeatpos % 2 != 0) {
						Serial.println(F("ERROR"));
					} else {
						Serial.println(F("REPEAT"));
						Serial.flush();
						set_irmux(muxval);
						irsend.enableIROut(emitfreq);
						space_long(irsend, SETTLE_DURATION);
						sendraw_mult(irsend, irparams.rawbuf, codepos, CODE_DIV);
						while (!Serial.available()) {
							sendraw_mult(irsend, irparams.rawbuf + codepos, repeatpos, CODE_DIV);
						}
						Serial.read();
						Serial.println(F("OK"));
							
					}
				} else {
					Serial.println(F("OK"));
					
					Serial.flush();
					set_irmux(muxval);
					irsend.enableIROut(emitfreq);
					space_long(irsend, SETTLE_DURATION);
					sendraw_mult(irsend, irparams.rawbuf, codepos, CODE_DIV);
				}
				parser_reset();
			}
		}
	}
}

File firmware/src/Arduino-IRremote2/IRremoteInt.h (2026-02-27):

//******************************************************************************
// IRremote
// Version 2.0.1 June, 2015
// Copyright 2009 Ken Shirriff
// For details, see http://arcfn.com/2009/08/multi-protocol-infrared-remote-library.html
//
// Modified by Paul Stoffregen <paul@pjrc.com> to support other boards and timers
//
// Interrupt code based on NECIRrcv by Joe Knapp
// http://www.arduino.cc/cgi-bin/yabb2/YaBB.pl?num=1210243556
// Also influenced by http://zovirl.com/2008/11/12/building-a-universal-remote-with-an-arduino/
//
// JVC and Panasonic protocol added by Kristian Lauszus (Thanks to zenwheel and other people at the original blog post)
// Whynter A/C ARC-110WD added by Francesco Meschia
//******************************************************************************

#ifndef IRremoteint_h
#define IRremoteint_h

//------------------------------------------------------------------------------
// Include the right Arduino header
//
#if defined(ARDUINO) && (ARDUINO >= 100)
#	include <Arduino.h>
#else
#	if !defined(IRPRONTO)
#		include <WProgram.h>
#	endif
#endif

//------------------------------------------------------------------------------
// This handles definition and access to global variables
//
#ifdef IR_GLOBAL
#	define EXTERN
#else
#	define EXTERN extern
#endif

//------------------------------------------------------------------------------
// Information for the Interrupt Service Routine
//
#define RAWBUF  512  // Maximum length of raw duration buffer

// Jays Note:
// Since this microcontroller is doing IR stff and just IR stuff, I get to take some somewhat extreme measures.
// I've got a TV. An Advent Q1435A. Its remote spams out its codes pretty quickly. So quickly, in fact, that it
// starts clobbering the contents of rawbuf before I'm finished dumping out the previous code's contents.
// My solution to this? Declare TWO separate rawbufs, and alternate between them whenever IRrecv::decode() is called.
typedef struct {
	// The fields are ordered to reduce memory over caused by struct-padding
	uint8_t       rcvstate;        // State Machine state
	uint8_t       recvpin;         // Pin connected to IR data from detector
	uint8_t       blinkpin;
	uint8_t       blinkflag;       // true -> enable blinking of pin on IR processing
	uint8_t       rawlen;          // counter of entries in rawbuf
	unsigned int  timer;           // State timer, counts 50uS ticks.
	volatile unsigned int  *rawbuf;  // pointer to the start of the currently active rawbuf
	unsigned int  rawbuf_a[RAWBUF];  // raw data A
	unsigned int  rawbuf_b[RAWBUF];  // raw data B
	uint8_t       overflow;        // Raw buffer overflow occurred
} irparams_t;

// ISR State-Machine : Receiver States
#define STATE_IDLE      2
#define STATE_MARK      3
#define STATE_SPACE     4
#define STATE_STOP      5
#define STATE_OVERFLOW  6

// Allow all parts of the code access to the ISR data
// NB. The data can be changed by the ISR at any time, even mid-function
// Therefore we declare it as "volatile" to stop the compiler/CPU caching it
EXTERN  volatile irparams_t  irparams;

//------------------------------------------------------------------------------
// Defines for blinking the LED
//

#if defined(CORE_LED0_PIN)
#	define BLINKLED        CORE_LED0_PIN
#	define BLINKLED_ON()   (digitalWrite(CORE_LED0_PIN, HIGH))
#	define BLINKLED_OFF()  (digitalWrite(CORE_LED0_PIN, LOW))

#elif defined(__AVR_ATmega1280__) || defined(__AVR_ATmega2560__)
#	define BLINKLED        13
#	define BLINKLED_ON()   (PORTB |= B10000000)
#	define BLINKLED_OFF()  (PORTB &= B01111111)

#elif defined(__AVR_ATmega644P__) || defined(__AVR_ATmega644__)
#	define BLINKLED        0
#	define BLINKLED_ON()   (PORTD |= B00000001)
#	define BLINKLED_OFF()  (PORTD &= B11111110)

#else
#	define BLINKLED        13
	#define BLINKLED_ON()  (PORTB |= B00100000)
#	define BLINKLED_OFF()  (PORTB &= B11011111)
#endif

//------------------------------------------------------------------------------
// CPU Frequency
//
#ifdef F_CPU
#	define SYSCLOCK  F_CPU     // main Arduino clock
#else
#	define SYSCLOCK  16000000  // main Arduino clock
#endif


//------------------------------------------------------------------------------
// Pulse parms are ((X*50)-100) for the Mark and ((X*50)+100) for the Space.
// First MARK is the one after the long gap
// Pulse parameters in uSec
//

// Due to sensor lag, when received, Marks  tend to be 100us too long and
//                                   Spaces tend to be 100us too short
#define MARK_EXCESS    100

// microseconds per clock interrupt tick
#define USECPERTICK    50

// Minimum gap between IR transmissions
//#define _GAP            5000
#define _GAP            10000
#define GAP_TICKS       (_GAP/USECPERTICK)

//------------------------------------------------------------------------------
// IR detector output is active low
//
#define MARK   0
#define SPACE  1

#define TIMER_RESET
#define TIMER_ENABLE_PWM   (TCCR1A |= _BV(COM1A1))
#define TIMER_DISABLE_PWM  (TCCR1A &= ~(_BV(COM1A1)))

#define TIMER_ENABLE_INTR   (TIMSK1 = _BV(OCIE1A))
#define TIMER_DISABLE_INTR  (TIMSK1 = 0)

//-----------------
#define TIMER_INTR_NAME       TIMER1_COMPA_vect

#define TIMER_CONFIG_KHZ(val) ({ \
	const uint16_t pwmval = SYSCLOCK / 2000 / (val); \
	TCCR1A                = _BV(WGM11); \
	TCCR1B                = _BV(WGM13) | _BV(CS10); \
	ICR1                  = pwmval; \
	OCR1A                 = pwmval / 3; \
})

#define TIMER_CONFIG_NORMAL() ({ \
	TCCR1A = 0; \
	TCCR1B = _BV(WGM12) | _BV(CS10); \
	OCR1A  = SYSCLOCK * USECPERTICK / 1000000; \
	TCNT1  = 0; \
})

#define TIMER_PWM_PIN  9

#endif

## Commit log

2026-02-27 Initial commit of combined project
    [ir-buddy-B_Cu.gbr, ir-buddy-B_Mask.gbr, ir-buddy-B_Paste.gbr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]
2026-02-27 * Added a background to board diagram.svg.
2026-02-28 * Added a .gitignore file. * Renamed many files in the firmware subdirectory to make things compatible with Arduino IDE. * Improved instructions for building and loading the firmware.
2026-03-06 * Fixed a minor timing issue with repeating codes
    [firmware.ino]
2026-03-06 There. Timing really fixed. I hope.
    [firmware.ino]
2026-05-12 * Fixed a bug where the microcontroller would come up with the IR LEDs active. * Added a DEBUG_MUX preprocessor directive. * Fixed the mux pin assignments. Oops.
    [firmware.ino]
